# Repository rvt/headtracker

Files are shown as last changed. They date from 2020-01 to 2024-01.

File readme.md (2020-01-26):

# Head tracking with esp8266/esp8265 and MPU6050 or MPU9250

# Installation

Install platform IO

```bash
# Build char* array for web
./generateHtmlArray.sh
platformio run --target upload -e wemos
platformio device monitor --baud 115200
```

# How to use

The device will create a new network so for a once time setup you need to have your computer or mobile phone connect to this network and congirue the wifi.

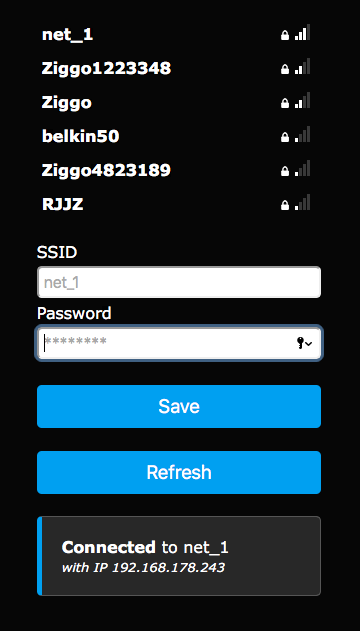
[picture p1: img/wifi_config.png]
Wifi Config Menu Wifi Config


If you did monitor your device it will show you the IP address of the access point.

While you are at it go to the setup page to tell setup the location and protocol to send data to. You can also calibrate the MPU (Motion Processing Unit). Read the instructions carefully!

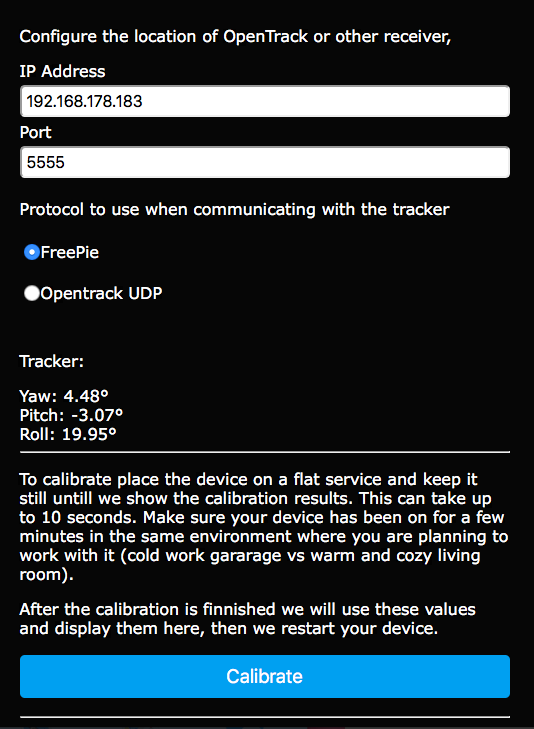
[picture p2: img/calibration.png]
Calibration menu Calibration


* FreePie protocol sends Yaw Pitch and Roll using the FreePie format. This has been tested with OpenTrack
* OpenTrackUDP sends Yaw Pitch and Roll using a simple floar array. This has been tested with OpenTrack.

# Where to put the MPU

I have designed a little box that can be printed using a 3D printer.
It´s a bit tricky to print but it will work out if you put up some support material. The STL file (mpu6050_holder.stl) is included. Then I have sewed it on a baseball cap. I´s very light and you will hardly fill it.

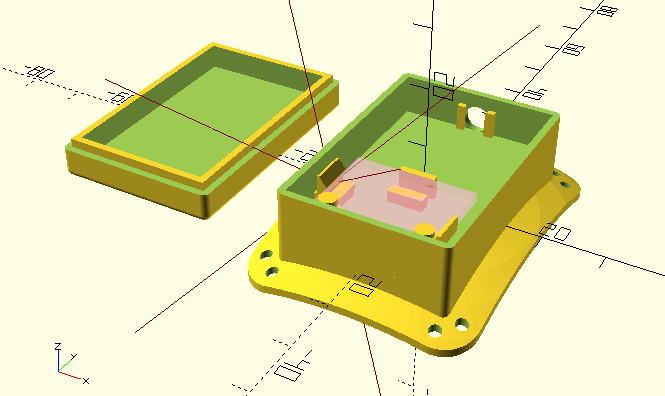
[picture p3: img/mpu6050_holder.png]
Holder for MPU6050 menu mpu6050


The ESP8266 can be put in a other box and you can connect the MPU6050 and ESP8266 using a 5 wire shielded cable. Make sure it´s not longer than 1.5 to 2 meter (I have tested 1.5m) otherwhise I2C communication mght fail.

# calibration and zero

Within the setup page there is a tool to setup calibration and setting 'zero' orientation.
Calibration of the mpu9250 is unfortunatly more than tricky, but if you have questions please ask.

# TODO
* guide trought calibration for imu's
* show calibration values on UI + quality of qualibration (mpu 9250)
* add more IMU's like the ICM-20948
* code cleanup, this was somewhat hacked together to create a MVP
* add more output protocols.

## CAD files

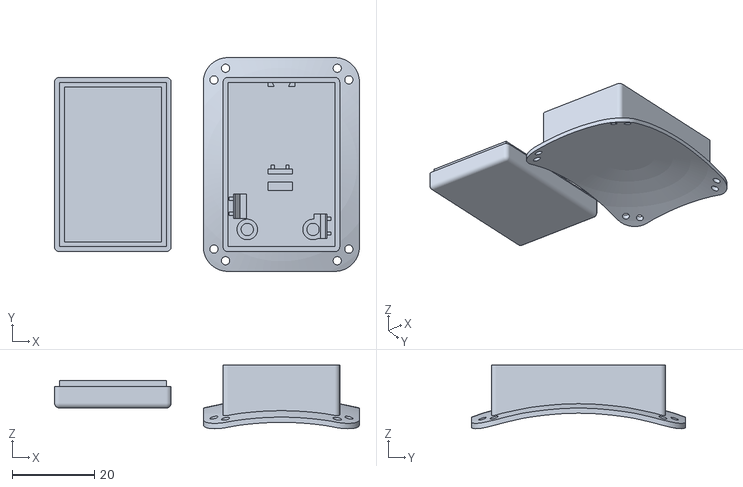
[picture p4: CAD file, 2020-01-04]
headtrack-mpu6050.stl
74.2 x 52.0 x 15.5

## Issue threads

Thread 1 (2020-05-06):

shows MPU-9250 connected.. but no YPR info showing

Bacon8tor, 2020-05-06:
I have uploaded the sketch, and connected to wifi, accessing the setup pages. Under tracker yaw , pitch and roll all show 0degrees. When I click calibrate the webpage says "Unknown error" but the Serial Monitor goes through the calibration, leaving on flat surface then waving in figure 8.
I am using a Wemos d1 r1 mini [https://miro.medium.com/max/2576/1*YKc8KpAfMrlhrOLmNjdRwQ.png](url)  and mpu 9250
pins are wired as such
wemos ----- mpu9250
GND ---- GND
3.3v --- VCC
D1 ---- SCL
D2 --- SDA

I wasnt sure if the INT pin was needed but doesnt look like it. I also tried opening up opentrack but still there no data looks like it was being sent as it stayed at 0 for all YPR. I couldnt find a good place to try and debug and possible Serial print the data from the mpu.

Appreciate any help, this project is exactly what i started to try and do myself, but came across this and was way more put together than what I had.

here is the serial monitor output.

```
*WM: [2] Connection result: WL_CONNECTED

*WM: [3] lastconxresult: WL_CONNECTED
*WM: [1] AutoConnect: SUCCESS
*WM: [1] STA IP Address: 10.10.11.234
connected...yeey :)
*WM: [1] Starting Web Portal
*WM: [3] dns server started with ip:
*WM: [2] HTTP server started
*WM: [2] WiFi Scan completed in 2194 ms
mounted file system
reading config file
opened config file
{
  "tracker_server": "10.10.10.165",
  "tracker_port": "5555",
  "tracker_protocol": "freepie",
  "mpu9250": {
    "AB0": -0.112976,
    "AB1": -0.224731,
    "AB2": -0.070923,
    "GB0": -1.427481,
    "GB1": 1.961832,
    "GB2": 2.908397,
    "MB0": -257.3269,
    "MB1": 143.7481,
    "MB2": 187.0547,
    "MS0": 1.001961,
    "MS1": 0.887153,
    "MS2": 1.143177
  },
  "zero": {
    "yaw": 0,
    "pitch": 0,
    "roll": 0,
    "x": 0,
    "y": 0,
    "z": 0
  }
}has tracker location
Initializing MPU9250...
Scanning...
I2C device found at address 0x68  !
done

MPU9250 9-axis motion sensor...
MPU9250 is online...
x-axis self test: acceleration trim within : 1.0% of factory value
y-axis self test: acceleration trim within : 1.1% of factory value
z-axis self test: acceleration trim within : 1.6% of factory value
x-axis self test: gyration trim within : 8.7% of factory value
y-axis self test: gyration trim within : 11.1% of factory value
z-axis self test: gyration trim within : 1.0% of factory value
Using saved calibration.
MPU9250 initialized for active data mode....
AK8963 I AM 48 I should be 48
AK8963 initialized for active data mode....
DMP Ready!*WM: [2] <- HTTP Root
*WM: [3] -> 10.10.11.234
*WM: [3] lastconxresult: WL_CONNECTED
*WM: [2] WiFi Scan completed in 2195 ms
*WM: [2] <- HTTP Param
*WM: [3] lastconxresult: WL_CONNECTED
*WM: [3] Sent param page
About to start calibrating gyro and accelerator, keep device flat and still!!!
Starting....
Finnished in 0.4 seconds
About to start calibrating magnetic compass, Wave device in a figure eight until done!
Starting....
Mag Calibration: Wave device in a figure eight until done!
Mag Calibration done!
Finnished in 22.5 seconds
saving config

 ets Jan  8 2013,rst cause:2, boot mode:(3,7)

load 0x4010f000, len 3656, room 16
tail 8
chksum 0x0c
csum 0x0c
v9c56ed1f
~ld

 Starting
*WM: [3] allocating params bytes: 20
*WM: [2] Added Parameter:
*WM: [2] Added Parameter: track_server
*WM: [2] Added Parameter: track_port
*WM: [2] Added Parameter: track_protocol
*WM: [2] Added Parameter:
*WM: [1] <form action='/wifi'    method='get'><button>Configure WiFi</button></form><br/>
<form action='/0wifi'   method='get'><button>Configure WiFi (No Scan)</button></form><br/>
<form action='/info'    method='get'><button>Info</button></form><br/>
<form action='/param'   method='get'><button>Setup</button></form><br/>
<hr><br/><form action='/erase'   method='get'><button class='D'>Erase</button></form><br/>
<form action='/restart' method='get'><button>Restart</button></form><br/>

*WM: [1] AutoConnect
*WM: [2] esp_wifi_set_country: US
*WM: [2] Connecting as wifi client...
*WM: [3] STA static IP:
*WM: [2] setSTAConfig static ip not set, skipping
*WM: [1] Connecting to SAVED AP: OHS_WiFi
*WM: [3] Using Password: 0rangut@n
*WM: [3] WiFi station enable
*WM: [3] enableSTA PERSISTENT ON
*WM: [1] connectTimeout not set, ESP waitForConnectResult...
*WM: [2] Connection result: WL_CONNECTED
*WM: [3] lastconxresult: WL_CONNECTED
*WM: [1] AutoConnect: SUCCESS
*WM: [1] STA IP Address: 10.10.11.234
connected...yeey :)
*WM: [1] Starting Web Portal
*WM: [3] dns server started with ip:
*WM: [2] HTTP server started
*WM: [2] WiFi Scan completed in 2193 ms
mounted file system
reading config file
opened config file
{
  "tracker_server": "10.10.10.165",
  "tracker_port": "5555",
  "tracker_protocol": "freepie",
  "mpu9250": {
    "AB0": -1.142944,
    "AB1": -0.092163,
    "AB2": -0.892395,
    "GB0": 0.099237,
    "GB1": 0.717557,
    "GB2": 1.229008,
    "MB0": 21.29602,
    "MB1": 944.123,
    "MB2": 125.2752,
    "MS0": 1.102136,
    "MS1": 0.621141,
    "MS2": 2.071553
  },
  "zero": {
    "yaw": 0,
    "pitch": 0,
    "roll": 0,
    "x": 0,
    "y": 0,
    "z": 0
  }
}has tracker location
Initializing MPU9250...
Scanning...
I2C device found at address 0x0C  !
I2C device found at address 0x68  !
done

MPU9250 9-axis motion sensor...
MPU9250 is online...
x-axis self test: acceleration trim within : 1.9% of factory value
y-axis self test: acceleration trim within : 0.3% of factory value
z-axis self test: acceleration trim within : 1.2% of factory value
x-axis self test: gyration trim within : 8.6% of factory value
y-axis self test: gyration trim within : 11.2% of factory value
z-axis self test: gyration trim within : 0.7% of factory value
Using saved calibration.
MPU9250 initialized for active data mode....
AK8963 I AM 48 I should be 48
AK8963 initialized for active data mode....
DMP Ready!
```

Bacon8tor, 2020-05-06:
well after just going thru the code line by line, backtracing. The interrupt pin should be connect. and now it is showing the YPR values. but Hitting calibrate still shows unknown error on webpage, and in serial monitor finishes in .4 seconds
`About to start calibrating gyro and accelerator, keep device flat and still!!!
Starting....
Finnished in 0.4 seconds`
which doesnt seem right to me, the mag calibration runs for 22 seconds.
after I run those I zero out looking at the screen. Once I have it connected to Opentrack, it connects and pushes data, pitch and roll seem good, but yaw doesnt.
If I turn to the left the tracker turns to the left but then quickly goes back to center without me moving my head back to center.  and looking at the webpage, yaw will move to -51deg, then quickly to -8deg without me moving.
I suspect the accel and gyro calibration are not running. Although I dont know why, I have tried several times and it deosnt seem to be updating and  I assume this is why the self test shows values and they dont change cause its using the default ones stored.

Again if possible would love a litle help or point in something I can try to do. maybe even run a calibration then be able to plug the numbers into the code, to be able to test it if fixes the issue

rvt, 2020-05-06:
Hey,

I never could get the MPU9250 working really well and I think there is something wonky on the library I used . I always head getter result with the 6050, but that one always start to drift away.
The 6050 does have internal quaternionFilters that seems to be better...

Note: When doing the figure 8, it's lik s roller coaster figure 8. The, do move it up-side-down. Essentially the device need to be pointed in all directions... Just to be clear :)

The interupt pin indeed should be connected : See https://github.com/rvt/headtracker/blob/master/src/main.cpp top few lines

All-in-all I could never get this head tracking itself to work rock stable.. Always some drift or some oddity when playing for a longer period

Bacon8tor, 2020-05-06:
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

Thanks for replying, yea I did find that line for the interrupt. I have been using the 6050, and have he same experience with drift. it works fairly well but the drift creeps so have to recenter it while playing. Thats why I tried the 9250 because the mag suppose to help with that, but i am having the same problems with the libraries, and just in general getting it to work.

I had a thought about trying to use them both a 6050 and 9250 but that see counter-intuitive since the 9250 should be a 6050 plus a mag, but doesn't seem that way.

The instant recentering Im getting with this project seems really weird, its not like the normal drift its almost instant I turn the device and once I stop its instantly moving back to center. Not sure whats causing that. But holding it in one spot seems fairly stable , the 6050 for me starts to drift quite a bit, and havent been able to find a good sketch that can somehow compensate for it.

Wireless head tracking has been a game changer tho, even given the struggle. I love not having a wire and all and all im still in this way less than a trackIr system.

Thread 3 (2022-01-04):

Failed compiling due to fatal error in jscript.generated.h

muhdzakiy24, 2022-01-04:
Hello, I'm still new to VSC and platformIO environment. I was trying to compile this code, but it seems I have hit a roadblock here.
Before this, I got an error due to `https://github.com/tzapu/WiFiManager#development` but this problem is fixed by changing the URL. However, for this case I don't know what to do. Help will be appreciated :)

`> Executing task: C:\Users\skyguardian\.platformio\penv\Scripts\platformio.exe run <

Processing wemos (platform: espressif8266; framework: arduino; board: esp01_1m)
-----------------------------------------------------------------------------------------------------------------------------------------------------------------------------------Verbose mode can be enabled via `-v, --verbose` option
CONFIGURATION: https://docs.platformio.org/page/boards/espressif8266/esp01_1m.html
PLATFORM: Espressif 8266 (3.2.0) > Espressif Generic ESP8266 ESP-01 1M
HARDWARE: ESP8266 80MHz, 80KB RAM, 1MB Flash
PACKAGES:
 - framework-arduinoespressif8266 3.30002.0 (3.0.2)
 - tool-esptool 1.413.0 (4.13)
 - tool-esptoolpy 1.30000.201119 (3.0.0)
 - toolchain-xtensa 2.100300.210717 (10.3.0)
LDF: Library Dependency Finder -> https://bit.ly/configure-pio-ldf
LDF Modes: Finder ~ chain, Compatibility ~ soft
Found 43 compatible libraries
Scanning dependencies...
Dependency Graph
|-- <I2Cdevlib-MPU6050> 0.0.0-alpha+sha.fbde122cc5
|   |-- <I2Cdevlib-Core> 0.0.0-alpha+sha.460d810002
|   |   |-- <Wire> 1.0
|-- <Brzo I2C> 1.3.2
|-- <WiFiManager> 2.0.5-beta+sha.8452df7
|   |-- <DNSServer> 1.1.1
|   |   |-- <ESP8266WiFi> 1.0
|   |-- <ESP8266mDNS> 1.2
|   |   |-- <ESP8266WiFi> 1.0
|   |-- <ESP8266WebServer> 1.0
|   |   |-- <ESP8266WiFi> 1.0
|   |-- <ESP8266WiFi> 1.0
|-- <ArduinoJson> 6.18.5
|-- <hwtrack>
|   |-- <ArduinoJson> 6.18.5
|-- <i2cdevmpu6050>
|   |-- <ArduinoJson> 6.18.5
|   |-- <hwtrack>
|   |   |-- <ArduinoJson> 6.18.5
|-- <kriswiner>
|   |-- <Wire> 1.0
|   |-- <ArduinoJson> 6.18.5
|   |-- <hwtrack>
|   |   |-- <ArduinoJson> 6.18.5
|-- <ESP8266WiFi> 1.0
Building in release mode
Compiling .pio\build\wemos\src\main.cpp.o
Compiling .pio\build\wemos\liba83\ESP8266WiFi\ESP8266WiFiSTA-WPS.cpp.o
Compiling .pio\build\wemos\liba83\ESP8266WiFi\ESP8266WiFiSTA.cpp.o
Compiling .pio\build\wemos\liba83\ESP8266WiFi\ESP8266WiFiScan.cpp.o
Compiling .pio\build\wemos\liba83\ESP8266WiFi\WiFiClient.cpp.o
Compiling .pio\build\wemos\liba83\ESP8266WiFi\WiFiClientSecureBearSSL.cpp.o
Compiling .pio\build\wemos\liba83\ESP8266WiFi\WiFiServer.cpp.o
Compiling .pio\build\wemos\liba83\ESP8266WiFi\WiFiServerSecureBearSSL.cpp.o
src\main.cpp:25:10: fatal error: jscript.generated.h: No such file or directory

***************************************************************************
* Looking for jscript.generated.h dependency? Check our library registry!
*
* CLI  > platformio lib search "header:jscript.generated.h"
* Web  > https://platformio.org/lib/search?query=header:jscript.generated.h
*
***************************************************************************

   25 | #include "jscript.generated.h"
      |          ^~~~~~~~~~~~~~~~~~~~~
compilation terminated.
*** [.pio\build\wemos\src\main.cpp.o] Error 1
=========================================================================== [FAILED] Took 6.52 seconds ===========================================================================
The terminal process "C:\Users\skyguardian\.platformio\penv\Scripts\platformio.exe 'run'" terminated with exit code: 1.

Terminal will be reused by tasks, press any key to close it.
`

rvt, 2022-01-04:
Did you run generateHtmlArray.sh ?

skyguardian18, 2022-01-04:
Okay I've run the generateHtmlArray.sh now, but now I face other issue

`> Executing task: C:\Users\skyguardian\.platformio\penv\Scripts\platformio.exe run <

Processing wemos (platform: espressif8266; framework: arduino; board: esp01_1m)
------------------------------------------------------------------------------------------------------------------------------------------------------------------Verbose mode can be enabled via `-v, --verbose` option
CONFIGURATION: https://docs.platformio.org/page/boards/espressif8266/esp01_1m.html
PLATFORM: Espressif 8266 (3.2.0) > Espressif Generic ESP8266 ESP-01 1M
HARDWARE: ESP8266 80MHz, 80KB RAM, 1MB Flash
PACKAGES:
 - framework-arduinoespressif8266 3.30002.0 (3.0.2)
 - tool-esptool 1.413.0 (4.13)
 - tool-esptoolpy 1.30000.201119 (3.0.0)
 - toolchain-xtensa 2.100300.210717 (10.3.0)
LDF: Library Dependency Finder -> https://bit.ly/configure-pio-ldf
LDF Modes: Finder ~ chain, Compatibility ~ soft
Found 43 compatible libraries
Scanning dependencies...
Dependency Graph
|-- <I2Cdevlib-MPU6050> 0.0.0-alpha+sha.fbde122cc5
|   |-- <I2Cdevlib-Core> 0.0.0-alpha+sha.460d810002
|   |   |-- <Wire> 1.0
|-- <Brzo I2C> 1.3.2
|-- <WiFiManager> 2.0.5-beta+sha.8452df7
|   |-- <DNSServer> 1.1.1
|   |   |-- <ESP8266WiFi> 1.0
|   |-- <ESP8266mDNS> 1.2
|   |   |-- <ESP8266WiFi> 1.0
|   |-- <ESP8266WebServer> 1.0
|   |   |-- <ESP8266WiFi> 1.0
|   |-- <ESP8266WiFi> 1.0
|-- <ArduinoJson> 6.18.5
|-- <hwtrack>
|   |-- <ArduinoJson> 6.18.5
|-- <i2cdevmpu6050>
|   |-- <ArduinoJson> 6.18.5
|   |-- <hwtrack>
|   |   |-- <ArduinoJson> 6.18.5
|-- <kriswiner>
|   |-- <Wire> 1.0
|   |-- <ArduinoJson> 6.18.5
|   |-- <hwtrack>
|   |   |-- <ArduinoJson> 6.18.5
|-- <ESP8266WiFi> 1.0
Building in release mode
Compiling .pio\build\wemos\src\main.cpp.o
Generating LD script .pio\build\wemos\ld\local.eagle.app.v6.common.ld
Compiling .pio\build\wemos\liba5f\Wire\Wire.cpp.o
Compiling .pio\build\wemos\libad4\Brzo I2C\brzo_i2c.c.o
Compiling .pio\build\wemos\liba83\ESP8266WiFi\BearSSLHelpers.cpp.o
Compiling .pio\build\wemos\liba83\ESP8266WiFi\CertStoreBearSSL.cpp.o
Compiling .pio\build\wemos\liba83\ESP8266WiFi\ESP8266WiFi.cpp.o
Compiling .pio\build\wemos\liba83\ESP8266WiFi\ESP8266WiFiAP.cpp.o
Compiling .pio\build\wemos\liba83\ESP8266WiFi\ESP8266WiFiGeneric.cpp.o
.pio\libdeps\wemos\Brzo I2C\brzo_i2c.c: In function 'brzo_i2c_ACK_polling':
.pio\libdeps\wemos\Brzo I2C\brzo_i2c.c:774:2: warning: 'a_set' is used uninitialized in this function [-Wuninitialized]
  774 |  asm volatile (
      |  ^~~
.pio\libdeps\wemos\Brzo I2C\brzo_i2c.c:774:2: warning: 'a_temp1' is used uninitialized in this function [-Wuninitialized]
.pio\libdeps\wemos\Brzo I2C\brzo_i2c.c:774:2: warning: 'a_in_value' is used uninitialized in this function [-Wuninitialized]
.pio\libdeps\wemos\Brzo I2C\brzo_i2c.c:774:2: warning: 'a_bit_index' is used uninitialized in this function [-Wuninitialized]
.pio\libdeps\wemos\Brzo I2C\brzo_i2c.c: In function 'brzo_i2c_setup':
.pio\libdeps\wemos\Brzo I2C\brzo_i2c.c:1088:2: warning: 'a_set' is used uninitialized in this function [-Wuninitialized]
 1088 |  asm volatile (
      |  ^~~
.pio\libdeps\wemos\Brzo I2C\brzo_i2c.c:1088:2: warning: 'a_temp1' is used uninitialized in this function [-Wuninitialized]
.pio\libdeps\wemos\Brzo I2C\brzo_i2c.c: In function 'brzo_i2c_write':
.pio\libdeps\wemos\Brzo I2C\brzo_i2c.c:72:2: warning: 'a_set' may be used uninitialized in this function [-Wmaybe-uninitialized]
   72 |  asm volatile (
      |  ^~~
.pio\libdeps\wemos\Brzo I2C\brzo_i2c.c:72:2: warning: 'a_temp1' may be used uninitialized in this function [-Wmaybe-uninitialized]
.pio\libdeps\wemos\Brzo I2C\brzo_i2c.c:72:2: warning: 'a_in_value' may be used uninitialized in this function [-Wmaybe-uninitialized]
.pio\libdeps\wemos\Brzo I2C\brzo_i2c.c:72:2: warning: 'a_bit_index' may be used uninitialized in this function [-Wmaybe-uninitialized]
.pio\libdeps\wemos\Brzo I2C\brzo_i2c.c: In function 'brzo_i2c_read':
.pio\libdeps\wemos\Brzo I2C\brzo_i2c.c:394:2: warning: 'a_set' may be used uninitialized in this function [-Wmaybe-uninitialized]
  394 |  asm volatile (
      |  ^~~
.pio\libdeps\wemos\Brzo I2C\brzo_i2c.c:394:2: warning: 'a_temp1' may be used uninitialized in this function [-Wmaybe-uninitialized]
.pio\libdeps\wemos\Brzo I2C\brzo_i2c.c:394:2: warning: 'a_in_value' may be used uninitialized in this function [-Wmaybe-uninitialized]
.pio\libdeps\wemos\Brzo I2C\brzo_i2c.c:394:2: warning: 'a_bit_index' may be used uninitialized in this function [-Wmaybe-uninitialized]
Archiving .pio\build\wemos\libad4\libBrzo I2C.a
Compiling .pio\build\wemos\liba83\ESP8266WiFi\ESP8266WiFiGratuitous.cpp.o
src\main.cpp:27:10: fatal error: I2Cdev.h: No such file or directory

****************************************************************
* Looking for I2Cdev.h dependency? Check our library registry!
*
* CLI  > platformio lib search "header:I2Cdev.h"
* Web  > https://platformio.org/lib/search?query=header:I2Cdev.h
*
****************************************************************

   27 | #include "I2Cdev.h"
      |          ^~~~~~~~~~
compilation terminated.
*** [.pio\build\wemos\src\main.cpp.o] Error 1
=================================================================== [FAILED] Took 5.00 seconds ===================================================================The terminal process "C:\Users\skyguardian\.platformio\penv\Scripts\platformio.exe 'run'" terminated with exit code: 1.`

Do I need to install other dependencies?

skyguardian18, 2022-01-05:
UPDATE: I've tried to install the MPU6050, it seems it solve the problem above but now facing a new problem

> Executing task: C:\Users\skyguardian\.platformio\penv\Scripts\platformio.exe run <
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

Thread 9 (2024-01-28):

calibration and zero do not work properly, calibration lead to crash(or wdt?)

Zhaosn, 2024-01-28:
calibration and zero do not work properly, the calibration problem can be solved inelegantly by changing the if in line 231 to always true. But "TRACK_PEEK_URI" always 0, so the zero button is useless.

> change

```
if (hwTrack->isReady()) {
            doCalibrate = true;
```

> to

```
 if (1) {
            doCalibrate = true;
```
or something seems crash when hit calibrate  button in browser.

```
 Starting
*wm:AutoConnect
*wm:No wifi saved, skipping
*wm:AutoConnect: FAILED for  1 ms
*wm:StartAP with SSID:  WM_AutoConnectAP
*wm:AP IP address: 192.168.4.1
*wm:Starting Web Portal

--------------- CUT HERE FOR EXCEPTION DECODER ---------------

Exception (28):
epc1=0x40205493 epc2=0x00000000 epc3=0x00000000 excvaddr=0x00000000 depc=0x00000000

>>>stack>>>

ctx: cont
sp: 3ffffc30 end: 3fffffd0 offset: 0190
3ffffdc0:  4020f301 00000030 00000010 00000000
3ffffdd0:  0023002f 00000000 00000000 000f000f
3ffffde0:  00000000 00000000 00000000 fffffffe
3ffffdf0:  3fff29c4 3fff2b20 00000000 40212d58
3ffffe00:  3fff0fd8 00000000 00000000 00000000
3ffffe10:  3fff0fd8 3fff29c4 3fff2adc 40204fe1
3ffffe20:  00000000 3fff29c4 3fff296c 4020ce60
3ffffe30:  00000001 00000000 00000000 0023002f
3ffffe40:  00000000 00000000 3ffea4b4 3fff29a0
3ffffe50:  00000000 00006e44 00000000 00000001
3ffffe60:  3fff0fd8 3fff29a0 00000000 00000000
3ffffe70:  3fff0fd8 3fff29a0 3fff296c 4020f096
3ffffe80:  40220c14 00000000 00001388 40207322
3ffffe90:  3fff0fd8 3fff0fd8 3fff32d4 4021dc2b
3ffffea0:  3fff0fd8 00000000 402139be 00000000
3ffffeb0:  3fff0fd8 3fff0fd8 3fff0ed8 4020f301
3ffffec0:  00303231 3fffff0c 3fffff18 00000000
3ffffed0:  00000000 00000000 3ffea4b4 00000001
3ffffee0:  3fff0fd8 00000000 402139be 00000000
3ffffef0:  3fff0fd8 00000001 3fff0ed8 4020f721
3fffff00:  00000000 73646e6f 00000000 00000000
3fffff10:  000b000f 00000000 00000000 000b000f
3fffff20:  00000000 00000000 3fff0ed8 3fff0e84
3fffff30:  3ffea8de 00000000 00000001 4020b920
3fffff40:  00000000 00000000 00000000 3fff0e84
3fffff50:  3fff0e68 3fff133c 3fff0ed8 40204d82
3fffff60:  40201d54 3ffea6ed 4021fa10 4021fa08
3fffff70:  3ffea703 3ffea707 3ffea70d 3fff259c
3fffff80:  3fff25b8 3fff25b8 feefeffe feefeffe
3fffff90:  3fff25b8 00000000 feefeffe feefeffe
3fffffa0:  feefeffe feefeffe feefeffe 3fff14c8
3fffffb0:  3fffdad0 00000000 3fff149c 40213b40
3fffffc0:  feefeffe feefeffe 3fffdab0 4010126d
<<<stack<<<

--------------- CUT HERE FOR EXCEPTION DECODER ---------------

 ets Jan  8 2013,rst cause:2, boot mode:(3,6)

load 0x4010f000, len 3424, room 16
tail 0
chksum 0x2e
load 0x3fff20b8, len 40, room 8
tail 0
chksum 0x2b
csum 0x2b
v00069120
~ld

 Starting
*wm:AutoConnect
*wm:No wifi saved, skipping
*wm:AutoConnect: FAILED for  1 ms
*wm:StartAP with SSID:  WM_AutoConnectAP
*wm:AP IP address: 192.168.4.1
*wm:Starting Web Portal
```
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
The correct setup process is to set the computer's IP address and port in this screen before setting up the AP, is that right? Because I can't get in this setup screen after connecting the ap (browser input 192.168.1.*). I can now get stable output after modifying it according to the above, but this strange crash is confusing me, the problem seems to be in the "hwTrack->isReady()", the doCalibrate and calibrateMpu() functions not causing the problem.

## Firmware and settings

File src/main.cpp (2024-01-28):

/*
  GY-521  NodeMCU
  MPU6050 devkit 1.0
  board   WemosD1       Description
  ======= ==========    ====================================================
  VCC     VU (5V USB)   Not available on all boards so use 3.3V if needed.
  GND     G             Ground
  SCL     D1 (GPIO05)   I2C clock
  SDA     D2 (GPIO04)   I2C data
  XDA     not connected
  XCL     not connected
  AD0     not connected
  INT     D8 (GPIO15)   Interrupt pin

*/

#include <FS.h>
#include <WiFiUdp.h>
#include <WiFiManager.h> // https://github.com/tzapu/WiFiManager
#include <ArduinoJson.h>          //https://github.com/bblanchon/ArduinoJson
#include <stdio.h>

#include "udpStructures.h"

#include "jscript.generated.h"
#include "protocolSelect_html.generated.h"
// #include "I2Cdev.h"
#include <hwheadtrack.h>
#include <hwheadtrackmpu6050.h>
#include <hwheadtrackmpu9250.h>

#ifndef RAD_TO_DEG
#define RAD_TO_DEG (180.f / M_PI)
#endif

#define TRIGGER_PIN                   0         // Flash button in nodemcu
#define UPDATES_PER_SECOND            200
#define EFFECT_PERIOD_CALLBACK        (1000 / UPDATES_PER_SECOND)
#define TRACKER_CONFIG_FILENAME       "/tracker.json"
#define TRACKER_CONFIG_DOCUMENT_SIZE  1024
#define PROTOCOL_FREEPIE              "freepie"
#define PROTOCOL_OPENTRACKUDP         "opentrackudp"
#undef M_PI
#define M_PI 3.14159265358979323846f

#define JBONE_URI                      "/jscript.js"
#define TRACK_PEEK_URI                 "/peek"
#define STORE_CALIBRATION_URI          "/calibrate"
#define ZERO_URI                       "/zero"

// routine to ensure we send timed message to the tracker
uint32_t effectPeriodStartMillis = 0;
uint32_t transitionCounter = 1;    // Will acount UPDATES_PER_SECOND per second

// Used in configurations
bool shouldSaveConfig = false;     // Indicate when configuration should be saved
uint32_t shouldRestart = 0;        // Indicate that a service requested an restart. Set to millies() of current time and it will restart 500ms later
bool shouldReloadAddress = false;  // Indicate when we should reload trackerIpAddress and trackerPort
bool hasTrackerLocation = false;   // Indicate when the tracker IP and port is known and good

// Orientation of MPU in space, all in RAD
HWHeadTrack_Orientation lastMeasurement;    // Last measurement from MPU
HWHeadTrack_Orientation zeroLocation;       // Location at zero
HWHeadTrack_Orientation offsetLocation;     // Location after applying zeroLocation from lastMeasurement
std::unique_ptr<HWHeadTrack> hwTrack(nullptr);

// Used to send data over UDP
IPAddress trackerIpAddress;        // tracker IP address, should be reloaded on each config chance
uint16_t  trackerPort;             // tracker port number
bool doCalibrate = false;

// Configuration
StaticJsonDocument<TRACKER_CONFIG_DOCUMENT_SIZE> json;

// WiFI Manager
WiFiManager wm;

// A UDP instance to let us send and receive packets over UDP
WiFiUDP Udp;


WiFiManagerParameter custom_html("<p>Configure the location of OpenTrack or other receiver,</p>"); // only custom html
WiFiManagerParameter custom_track_server("track_server", "IP Address", nullptr, 40);
WiFiManagerParameter custom_track_port("track_port", "Port", nullptr, 6);

const char _customHtml_checkbox[] PROGMEM = "type=\"radio\"";

const char custoHeader[] = "<script src='/jscript.js'></script>";
WiFiManagerParameter custom_track_protocol("track_protocol", "", PROTOCOL_FREEPIE, 18, "type='hidden'");
WiFiManagerParameter custom_protocol_radio((char*)protocolSelect_html_nt);



void saveParamCallback() {
    Serial.println("[CALLBACK] saveParamCallback fired");

    if (strlen(custom_track_server.getValue()) > 0) {
        json["tracker_server"] = custom_track_server.getValue();
        json["tracker_port"] = custom_track_port.getValue();
        json["tracker_protocol"] = custom_track_protocol.getValue();
        shouldSaveConfig = true;
        shouldReloadAddress = true;
    }
}

/**
 * Load the tracker information into trackerPort and trackerIpAddress
 * return true if that condition is matched
 */
bool loadAddressInfoFromConfig() {
    if (json.containsKey("tracker_server")) {
        trackerPort = json["tracker_port"].as<int>();
        const char* tmp = json["tracker_server"].as<const char*>();
        return trackerIpAddress.fromString(tmp);
    }

    return false;
}

void sendDatagramToTracker(const  uint8_t* buffer, size_t size) {
    Udp.beginPacket(trackerIpAddress, trackerPort);
    Udp.write(buffer, size);
    Udp.endPacket();
}

/**
 * Send tracker information using FreePie datastructure
 */
void sendFreePieDatagram() {
    FreePie freepie {
        0,
        2,
        offsetLocation.yaw,
        offsetLocation.pitch,
        offsetLocation.roll,
        0, 0, 0,
        0, 0, 0, 0, 0, 0
    };
    sendDatagramToTracker((uint8_t*) &freepie, (size_t)sizeof(FreePie));
}

/**
 * Send a datagram using OpenTrack UDP data structure
 */
void sendOpentrackDatagram() {
    OpenTrack openTrack {
        0.0,
        0.0,
        0.0,
        offsetLocation.yaw * RAD_TO_DEG,
        offsetLocation.pitch * RAD_TO_DEG,
        offsetLocation.roll* RAD_TO_DEG
    };
    sendDatagramToTracker((uint8_t*) &openTrack, (size_t)sizeof(OpenTrack));
}

/**
 * Send to tracker if hasTrackerLocation is set to true
 */
void sendTracker() {
    if (!hasTrackerLocation) {
        return;
    }

    if (strcmp(custom_track_protocol.getValue(), PROTOCOL_OPENTRACKUDP) == 0) {
        sendOpentrackDatagram();
    } else {
        sendFreePieDatagram();
    }
}

void calibrateMpu() {
    if (!json.containsKey(hwTrack->name())) {
        json.createNestedObject(hwTrack->name());
    }

    JsonObject config = json[hwTrack->name()].as<JsonObject>();
    hwTrack->calibrate(config);

    shouldSaveConfig = true;
    shouldRestart = millis();
}




/**
 * When server comes online setup other routes
 */
void serverOnlineCallback() {
    wm.server->on(JBONE_URI, []() {
        wm.server->sendHeader("Content-Encoding", "gzip");
        wm.server->setContentLength(jscript_js_gz_len);
        wm.server->send(200, "application/javascript", "");
        wm.server->sendContent_P((char*)jscript_js_gz, jscript_js_gz_len);
    });

    wm.server->on(ZERO_URI, []() {
        zeroLocation = lastMeasurement;

        if (!json.containsKey("zero")) {
            json.createNestedObject("zero");
        }
        JsonObject config = json["zero"].as<JsonObject>();
        config["yaw"] = zeroLocation.yaw;
        config["pitch"] = zeroLocation.pitch;
        config["roll"] = zeroLocation.roll;
        config["x"] = zeroLocation.x;
        config["y"] = zeroLocation.y;
        config["z"] = zeroLocation.z;
        shouldSaveConfig = true;
        wm.server->send(200, "application/javascript", "{}");
    });

    wm.server->on(TRACK_PEEK_URI, []() {
        char payloadBuffer[128];
        sprintf(payloadBuffer, "{\"yaw\":%.2f,\"pitch\":%.2f,\"roll\":%.2f,\"x\":%.2f,\"y\":%.2f,\"z\":%.2f}",
                offsetLocation.yaw * RAD_TO_DEG,
                offsetLocation.pitch * RAD_TO_DEG,
                offsetLocation.roll * RAD_TO_DEG,
                offsetLocation.x,
                offsetLocation.y,
                offsetLocation.z
               );

        wm.server->setContentLength(strlen(payloadBuffer));
        wm.server->send(200, F("application/javascript"), payloadBuffer);
    });

    wm.server->on(STORE_CALIBRATION_URI, []() {
        if (hwTrack->isReady()) {
            doCalibrate = true;

            // Send result back
            // JsonObject config = json[hwTrack->name()].as<JsonObject>();
            // wm.server->setContentLength(measureJson(config));
            wm.server->send(200, F("application/javascript"), "");
            WiFiClient client = wm.server->client();
            // serializeJson(config, client);

        } else {
            // We would like to send a 503 but tje JS framework doesn´t give us the body
            wm.server->send(200, F("application/json"), F("{\"status\":\"error\", \"message\":\"MPU is not ready, please check hardware.\"}"));
        }
    });

}


/**
 * Load tracker configuration file and set the values in WifiManager Parameters
 */
bool loadTrackConfig() {
    if (SPIFFS.begin()) {
        Serial.println("mounted file system");

        if (SPIFFS.exists(TRACKER_CONFIG_FILENAME)) {
            //file exists, reading and loading
            Serial.println("reading config file");
            File configFile = SPIFFS.open(TRACKER_CONFIG_FILENAME, "r");

            if (configFile) {
                Serial.println("opened config file ");
                StaticJsonDocument<TRACKER_CONFIG_DOCUMENT_SIZE> jsonTmp;
                DeserializationError error = deserializeJson(jsonTmp, configFile);

                if (error) {
                    Serial.println(F("Failed to read file, using default configuration"));
                } else {
                    json = jsonTmp;
                    serializeJsonPretty(json, Serial);
                    return true;
                }
            }
        }
    }

    return false;
}


/**
 * Store custom oarameter configuration in SPIFFS
 */
bool saveConfigSPIFFS() {
    if (SPIFFS.begin()) {
        Serial.println("saving config");

        if (SPIFFS.begin()) {
            File configFile = SPIFFS.open(TRACKER_CONFIG_FILENAME, "w");

            if (!configFile) {
                Serial.println("failed to open config file for writing");
            } else {
                serializeJson(json, configFile);
                // serializeJsonPretty(json, Serial);
                configFile.close();
                return true;
            }
        }
    }

    return false;
}

void checkButton(){
  // check for button press
  if ( digitalRead(TRIGGER_PIN) == LOW ) {
    // poor mans debounce/press-hold, code not ideal for production
    delay(50);
    if( digitalRead(TRIGGER_PIN) == LOW ){
      Serial.println("Button Pressed");
      // still holding button for 3000 ms, reset settings, code not ideaa for production
      delay(3000); // reset delay hold
      if( digitalRead(TRIGGER_PIN) == LOW ){
        Serial.println("Button Held");
        Serial.println("Erasing Config, restarting");
        wm.resetSettings();
        ESP.restart();
      }
    }
  }
}

void setup() {

    WiFi.mode(WIFI_STA);
    Serial.begin(115200);
    delay(250);

    Serial.println("\n Starting");
    WiFi.setSleepMode(WIFI_NONE_SLEEP); // disable sleep, can improve ap stability

    pinMode(TRIGGER_PIN, INPUT);

    wm.setClass("invert");

    // custom_html.setValue("test",4);
    wm.setCustomHeadElement(custoHeader);

    //add all your parameters here
    wm.addParameter(&custom_html);
    wm.addParameter(&custom_track_server);
    wm.addParameter(&custom_track_port);
    wm.addParameter(&custom_track_protocol);
    wm.addParameter(&custom_protocol_radio);

    // callbacks
    wm.setSaveParamsCallback(saveParamCallback);

    std::vector<const char*> menu = {"wifi", "wifinoscan", "info", "param", "sep", "erase", "restart"};
    wm.setMenu(menu);

    // wm.setParamsPage(true); // move params to seperate page, not wifi, do not combine with setmenu!

    // set country
    wm.setCountry("US"); // setting wifi country seems to improve OSX soft ap connectivity, may help others as well

    wm.setWebServerCallback(serverOnlineCallback);

    // set configrportal timeout
    wm.setConfigPortalTimeout(120);

    if (!wm.autoConnect("WM_AutoConnectAP")) {
        Serial.println("failed to connect and hit timeout");
        wm.startConfigPortal();
    }

    //if you get here you have connected to the WiFi
    Serial.println("connected...yeey :)");
    wm.startWebPortal();

    // Load tracker configuration
    shouldReloadAddress = loadTrackConfig();
    if (shouldReloadAddress == true) {
        // Configu page will get the info from here
        custom_track_server.setValue(json["tracker_server"], 40);
        custom_track_port.setValue(json["tracker_port"], 5);
        custom_track_protocol.setValue(json["tracker_protocol"], 12);
    } else {
        Serial.println(F("COnfiguration not loaded, is this first time started?"));
    }

    // Load zero offset
    if (json.containsKey("zero")) {
        const JsonObject config = json["zero"].as<JsonObject>();
        zeroLocation.yaw = config["yaw"].as<float>();
        zeroLocation.pitch = config["pitch"].as<float>();
        zeroLocation.roll = config["roll"].as<float>();
        zeroLocation.x = config["x"].as<float>();
        zeroLocation.y = config["y"].as<float>();
        zeroLocation.z = config["z"].as<float>();
    }

    // join I2C bus (I2Cdev library doesn't do this automatically)
#if I2CDEV_IMPLEMENTATION == I2CDEV_ARDUINO_WIRE
    Wire.begin();
    Wire.setClock(400000); // 400kHz I2C clock. Comment this line if having compilation difficulties
#elif I2CDEV_IMPLEMENTATION == I2CDEV_BUILTIN_FASTWIRE
    Fastwire::setup(400, true);
#endif
    hwTrack.reset(new HWHeadTrackmpu6050());
    // hwTrack.reset(new HWHeadTrackmpu9250());

    effectPeriodStartMillis = millis();
}

#define NUMBER_OF_SLOTS 10
void loop() {
    checkButton();
    const uint32_t currentMillis = millis();

    if (currentMillis - effectPeriodStartMillis >= EFFECT_PERIOD_CALLBACK) {
        effectPeriodStartMillis = currentMillis;
        transitionCounter++;
        uint8_t slot = 0;

        if (hwTrack->loop()) {
            lastMeasurement = hwTrack->getOrientation();

            // We expect -180 to 180 degrees yaw where 0 is looking straight at the screen
            lastMeasurement.yaw -= M_PI;

            // calculate offset location
            offsetLocation.yaw = lastMeasurement.yaw - zeroLocation.yaw;
            offsetLocation.pitch = lastMeasurement.pitch - zeroLocation.pitch;
            offsetLocation.roll = lastMeasurement.roll - zeroLocation.roll;
            offsetLocation.x = lastMeasurement.x - zeroLocation.x;
            offsetLocation.y = lastMeasurement.y - zeroLocation.y;
            offsetLocation.z = lastMeasurement.z - zeroLocation.z;
        }

        sendTracker();

        if (transitionCounter % NUMBER_OF_SLOTS == slot++) {
            wm.process();
        } else if (transitionCounter % NUMBER_OF_SLOTS == slot++) {
            if (transitionCounter % UPDATES_PER_SECOND == slot - 1) {
                hwTrack->setup(json[hwTrack->name()]);
            }
        } else if (transitionCounter % NUMBER_OF_SLOTS == slot++) {
            if (doCalibrate) {
                doCalibrate = false;
                calibrateMpu();
            }
        } else if (transitionCounter % NUMBER_OF_SLOTS == slot++) {
            if (shouldSaveConfig) {
                shouldSaveConfig = false;
                saveConfigSPIFFS();
            } else if (shouldRestart != 0 && (currentMillis - shouldRestart >= 5000)) {
                shouldRestart = 0;
                ESP.restart();
            } else if (shouldReloadAddress) {
                shouldReloadAddress = false;
                hasTrackerLocation = loadAddressInfoFromConfig();
                Serial.println("has tracker location");
            }
        }
    }

}

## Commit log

2020-01-04 Show images
    [headtrack-mpu6050.stl]
2020-01-19 Fix calling filter sendTracker()
    [main.cpp]
2020-01-19 Add calibration for MPU9250 (work in progress)
2020-01-26 Fixed issue with calibration of mpu9250 Fixed possible issue with mpu offset, we will now do it in esp instead of mpu.
    [main.cpp]
2023-03-06 pin down dependencies for the build to succeed
2024-01-28 Add env nodemcu; fix ArduinoJson compile error
    [main.cpp]
2024-01-28 Use flash button as wifi resetSettings
    [main.cpp]
